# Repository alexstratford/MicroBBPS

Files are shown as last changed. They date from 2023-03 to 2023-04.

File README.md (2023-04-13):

# MicroBBPS
<h3>Breadboard Power Supply</h3>
<BR CLEAR=”left” />

A small, USB-C connected power supply designed to fit onto the power rails of a solderless breadboard.

For each side, you can select between 3.3 & 5.0 Volt linear regulators, or the input voltage at the screw terminal. 

The integrated version adds 26 breadboard rows and 2 continuous power rails. So you can turn those prototypes into something more permanent with an easy microUSB power connector.

<h4><a href="https://github.com/stasiselectronics/MicroBBPS/tree/variant-integrated">Check out the integrated version's repository branch</a></h4>

## Documentation

If you would like to read more about how the design works and see some of the technical information, be sure to check out the documentation site that accompanies this project.

<h3><a href="https://stasiselectronics.github.io/MicroBBPS/">Read the Docs</a></h3>

This site is hosted on Github Pages, a great way to deploy your own static website using jekyll. It uses the wonderful theme [Minimal Mistakes](https://mmistakes.github.io/minimal-mistakes/about/) by Michael Rose.

[Learn more about github pages.](https://pages.github.com/)

## Development
This open source hardware project is developed using KiCAD and inkscape. It exists as a schematic and pcb design, with supporting files to create the necesarry output files for Printed Circuit Board fabrication.

[Learn more about KiCAD](https://kicad.org/about/kicad/)

## Updates
If you would like to keep up to date with this project, be sure to check out the original creator's instagram

<h3><a href="https://www.instagram.com/stasis.electronics/">stasis.electronics</a></h3>

### A02 Fabrication

After incorporating the design changes from the first revision, the second revision came out great! 

There are still a few details to try and adjust for any future fabrication.
- Silkscreen adjustments for better image fidelity
- Still have some mechanical rocking on the solderless version when inserted into a breadboard

Some of the major changes between on A02 from A01 are
- Smaller board shape
- Changed LEDs to 1206 for better part availability and easier hand soldering
- Larger silkscreen features
- Integrated version

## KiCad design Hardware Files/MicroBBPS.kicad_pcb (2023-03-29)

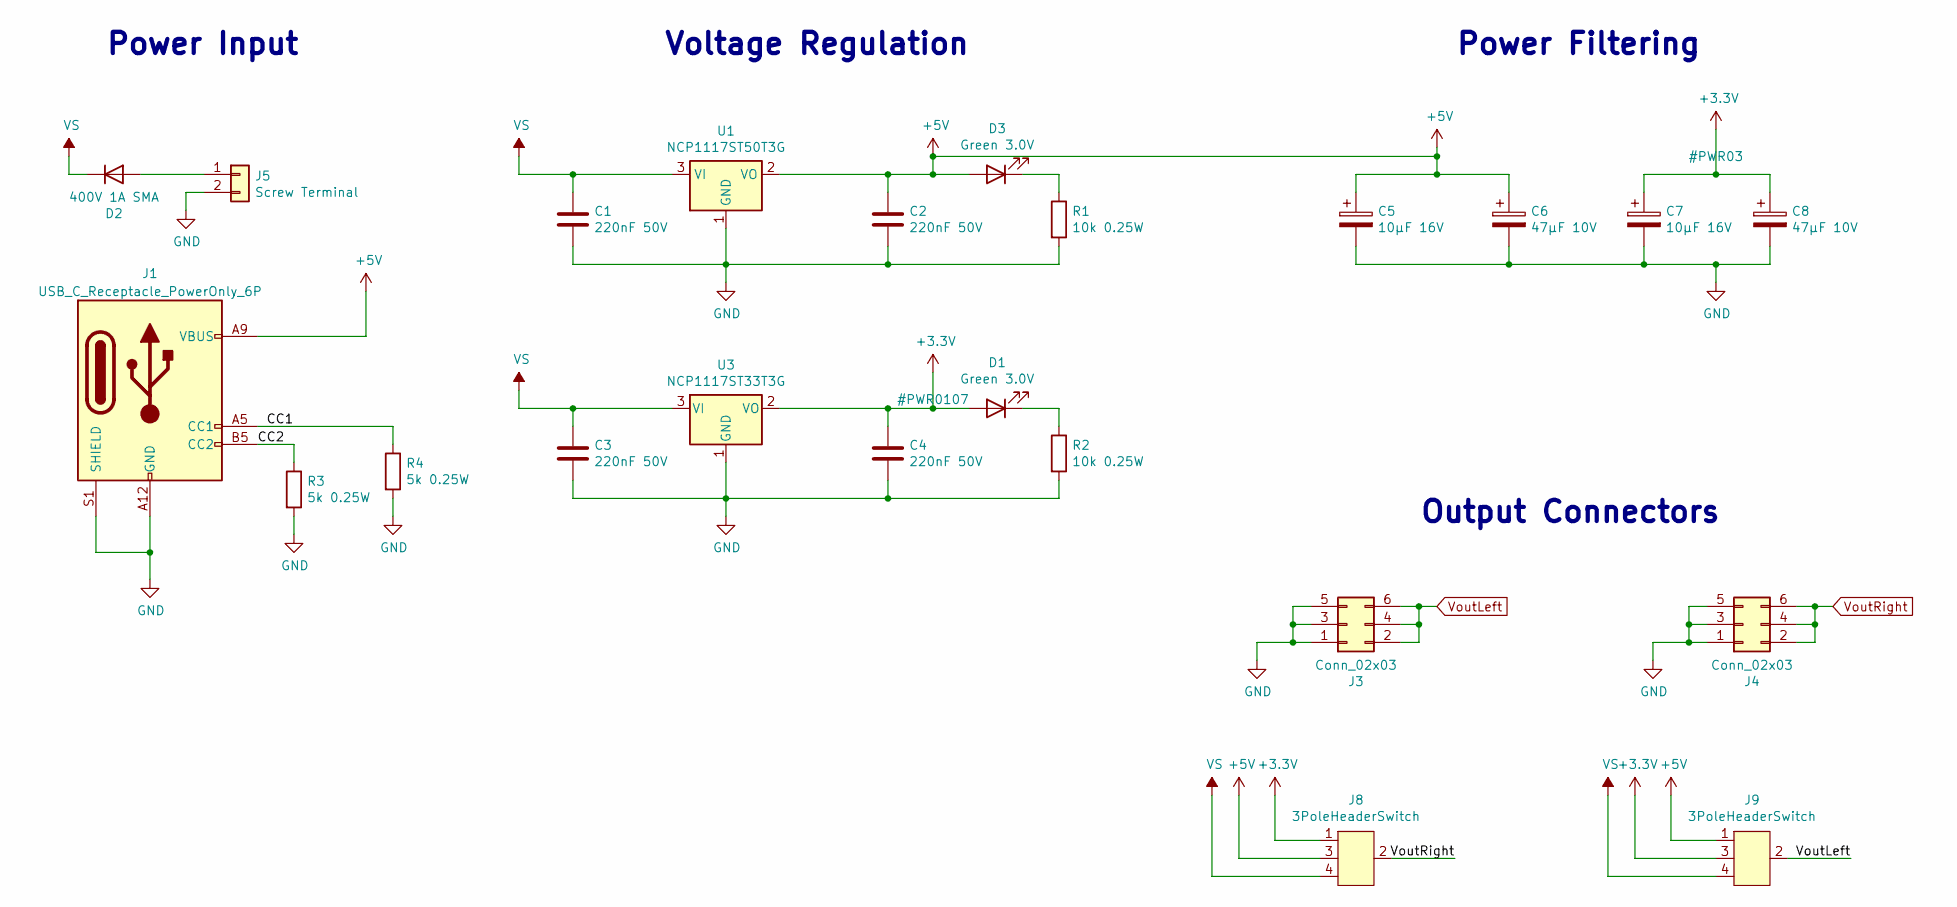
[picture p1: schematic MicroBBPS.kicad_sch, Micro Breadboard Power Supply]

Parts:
C1, C2, C3, C4: 220nF 50V; C_1206_3216Metric_Pad1.33x1.80mm_HandSolder
C5, C7: 10µF 16V; CP_Elec_4x5.4
C6, C8: 47µF 10V; CP_Elec_4x5.4
D1, D3: Green 3.0V; D_1206_3216Metric_Pad1.42x1.75mm_HandSolder
D2: 400V 1A SMA; D_SMA
J1: USB_C_Receptacle_PowerOnly_6P; GT-USB-7002C
J3, J4: Conn_02x03; PinHeader_2x03_P2.54mm_Vertical
J5: Screw Terminal; WJ124-3.81-2P
J8, J9: 3PoleHeaderSwitch
R1, R2: 10k 0.25W; R_1206_3216Metric_Pad1.30x1.75mm_HandSolder
R3, R4: 5k 0.25W; R_1206_3216Metric_Pad1.30x1.75mm_HandSolder
U1: NCP1117ST50T3G; SOT-223-3_TabPin2
U3: NCP1117ST33T3G; SOT-223-3_TabPin2

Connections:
+3.3V: C4.1, C7.1, C8.1, D1.2 (A), J8.1, J9.3, U3.2 (VO)
+5V: C2.1, C5.1, C6.1, D3.2 (A), J1.A9 (VBUS), J1.B9 (VBUS), J8.3, J9.1, U1.2 (VO)
/CC1: J1.A5 (CC1), R4.1
/CC2: J1.B5 (CC2), R3.1
GND: C1.2, C2.2, C3.2, C4.2, C5.2, C6.2, C7.2, C8.2, J1.A12 (GND), J1.B12 (GND), J1.S1 (SHIELD), J3.1, J3.3, J3.5, J4.1, J4.3, J4.5, J5.2, R1.2, R2.2, R3.2, R4.2, U1.1 (GND), U3.1 (GND)
unnamed: D1.1 (K), R2.1
unnamed: D2.2 (A), J5.1
unnamed: D3.1 (K), R1.1
VS: C1.1, C3.1, D2.1 (K), J8.4, J9.4, U1.3 (VI), U3.3 (VI)
VoutLeft: J3.2, J3.4, J3.6, J9.2
VoutRight: J4.2, J4.4, J4.6, J8.2

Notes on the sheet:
Output Connectors
Power Input
Voltage Regulation
Power Filtering

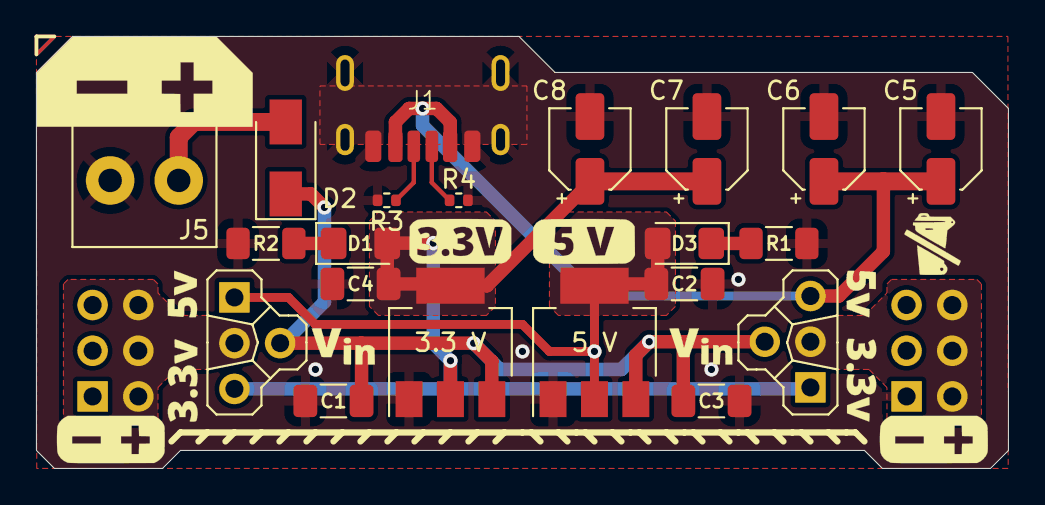
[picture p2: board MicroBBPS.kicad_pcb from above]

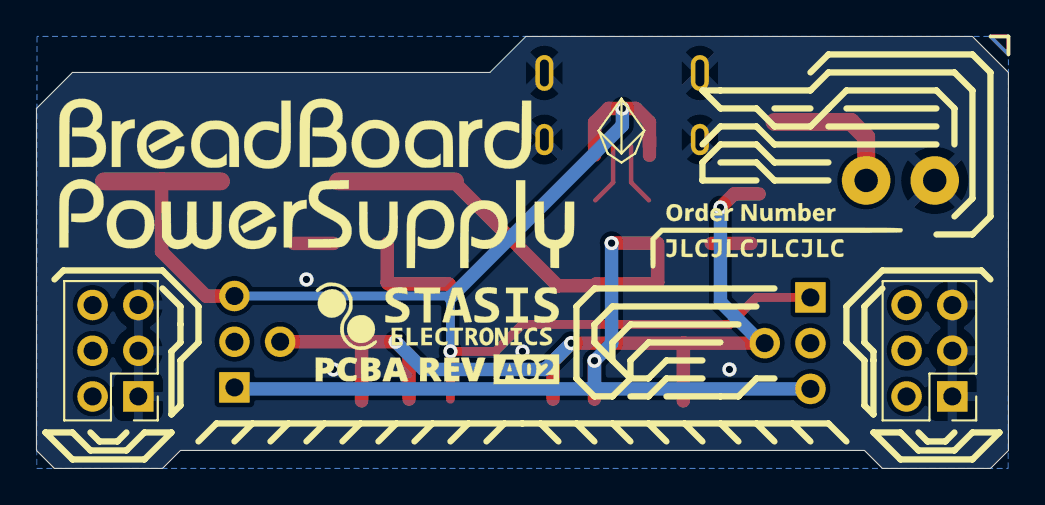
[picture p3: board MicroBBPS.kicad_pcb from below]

Board: 2 copper layers, 54.0 x 24.0 mm, 23 parts (2 on the bottom side), 11 nets.

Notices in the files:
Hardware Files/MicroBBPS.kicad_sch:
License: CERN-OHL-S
